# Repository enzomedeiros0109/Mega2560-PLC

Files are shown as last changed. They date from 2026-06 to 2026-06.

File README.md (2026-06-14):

# Placa de Circuito Impresso

| Esquemático | Visão Superior (Top) | Visão Inferior (Bottom) |
| :---: | :---: | :---: |
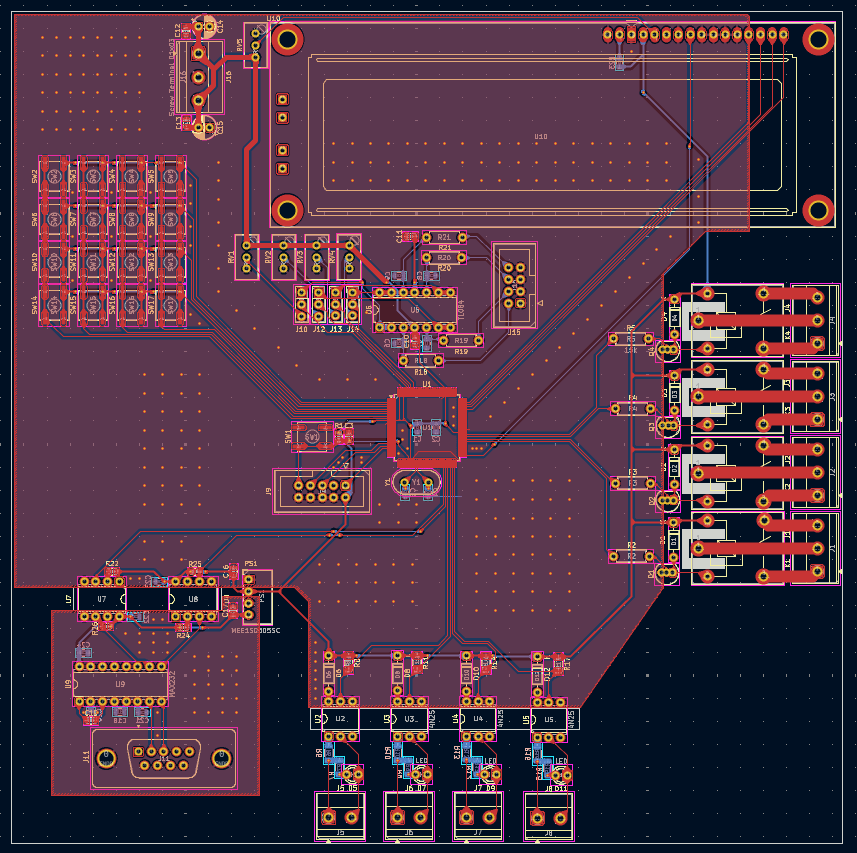
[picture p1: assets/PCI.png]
Esquemático da Placa de Circuito Impresso
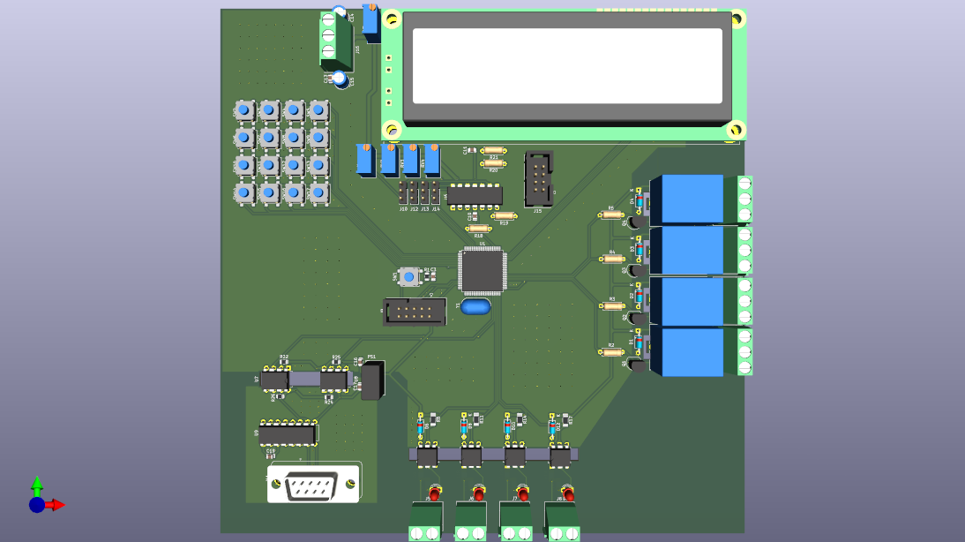
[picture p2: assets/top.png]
Visualização 3D da parte superior da PCB
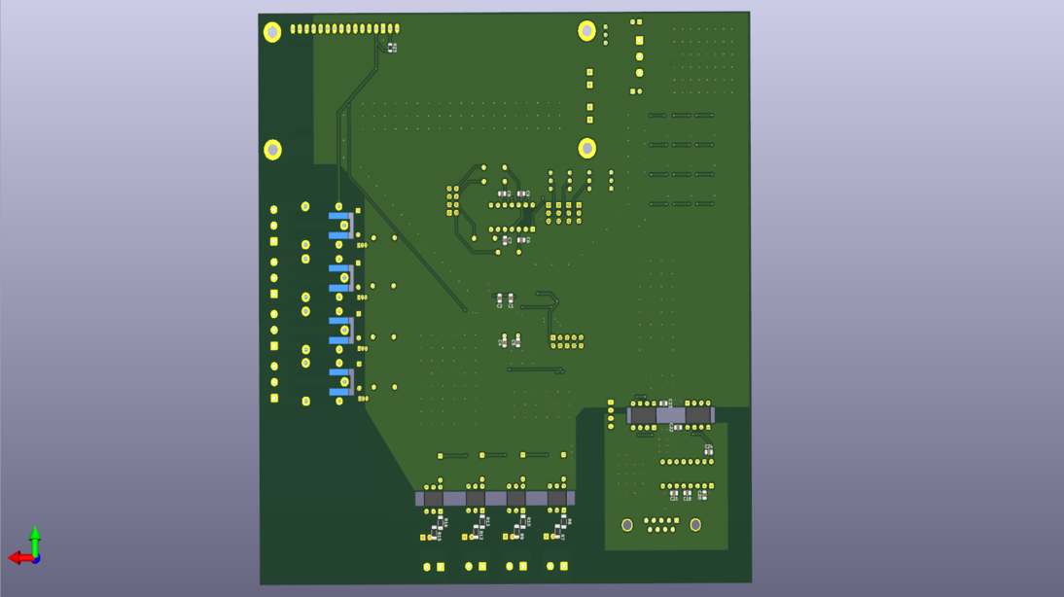
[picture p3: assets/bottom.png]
Visualização 3D da parte inferior da PCB
|  |  |  |

## Descrição

Este projeto consiste no design de uma Placa de Circuito Impresso (PCB) voltada para aplicações de controle, automação e desenvolvimento. A placa integra diversas interfaces de entrada, saída e comunicação em um único hardware, tornando-a ideal para controle de processos industriais, automação residencial ou projetos acadêmicos avançados.

## Principais Recursos

Essa placa foi o projeto final da cadeira de Construção de Dispositivos Digitais do curso de Engenharia da Computação. Ela contém:

* **Processamento Central:** Espaço dedicado para o microcontrolador principal (U1) com pinos de programação/debug e cristal oscilador (Y1).
* **Interface de Usuário (IHM):**
    * **Teclado Matricial 4x4:** Matriz de 16 botões (SW2 a SW17) para entrada de dados e navegação.
    * **Display LCD:** Interface no topo da placa (U10) para conexão de displays LCD (ex: 16x2 ou 20x4).
* **Acionamento de Potência:**
    * **4x Relés Independentes:** (K1 a K4) com conectores tipo borne para acionamento seguro de cargas AC/DC externas.
* **Isolamento e Segurança:**
    * **Entradas/Saídas Optoisoladas:** CI's dedicados (U2 a U5) para proteção do circuito lógico contra ruídos e picos de tensão das interfaces externas.
* **Comunicação:**
    * **Porta Serial RS-232:** Conector DB9 (J11) em conjunto com o driver MAX232 (U9) para comunicação com CLP's, computadores e equipamentos legados.
* **Tratamento de Sinais Analógicos:**
    * Circuito com Amplificador Operacional (TL084 - U6) e múltiplos trimpots (RV1 a RV4) para calibração, condicionamento e ajuste de ganhos de sensores analógicos.
* **Conectividade:**
    * Múltiplos terminais de parafuso (screw terminals) nas bordas da placa para facilitar a ligação de sensores, fontes de alimentação e atuadores.

## Características do projeto

* **Software:** KiCAD
* **Camadas:** Placa de dupla face (Top e Bottom layers visíveis pelas trilhas vermelhas e azuis).

## Estrutura do Projeto

```text
├── assets/
│   └── schematic_view.jpeg   # Imagens e renderizações da placa
│   └── top_view.jpeg         # Parte superior da placa
│   └── bottom_view.jpeg      # Parte inferior da placa
├── gerbers                   # Arquivos para fabricação da PCB
├── pasta do projeto          # Pasta com projeto KiCAD
└── Planilha de preços.ods    # Planilha com preço e link dos componentes
```

## Como abrir o arquivo

1. Faça o clone do repositório.
2. Acesse a pasta `pasta do projeto` abra `av3.kicad_pro`.

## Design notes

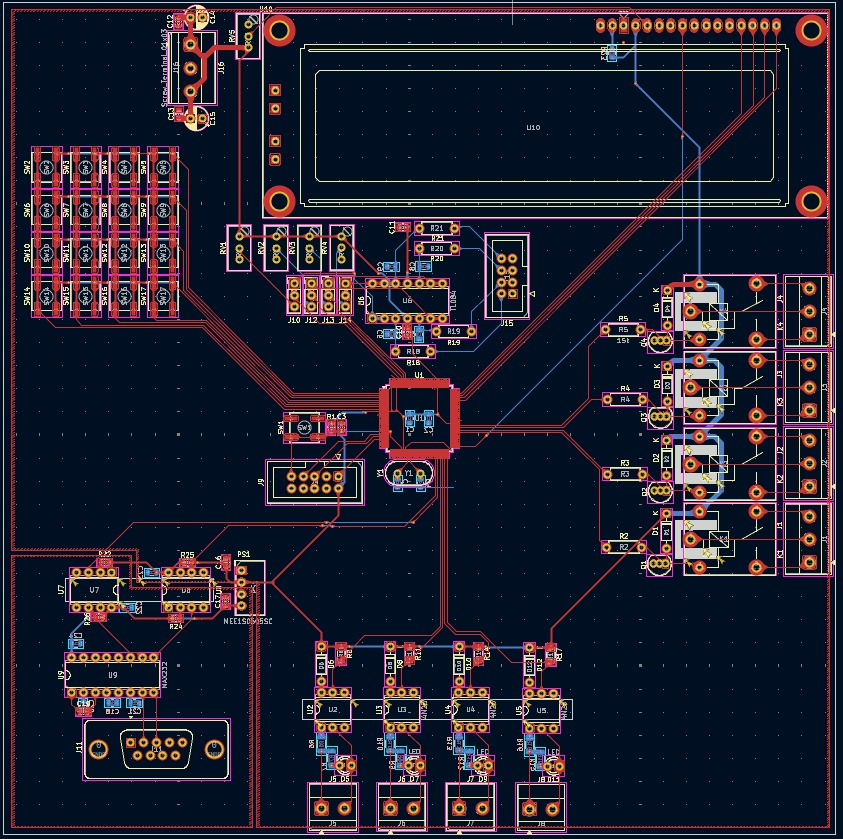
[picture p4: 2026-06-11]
assets/schematic_view.jpeg

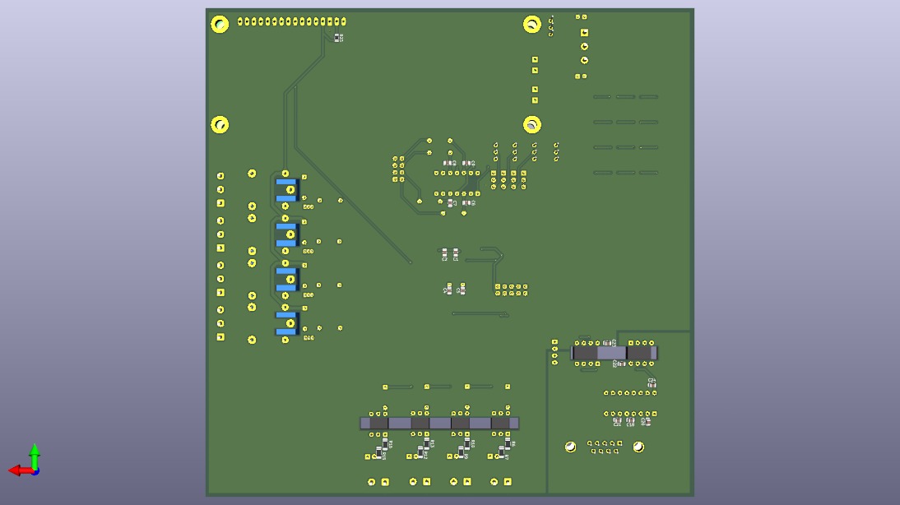
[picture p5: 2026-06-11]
assets/bottom_view.jpeg

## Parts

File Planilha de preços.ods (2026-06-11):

Footprint |  | Valores | Qtd na placa | Preço (Reais) | Qtd na compra | Custo total por componente (Reais) | Site
Capacitor_SMD | C_0805_2012Metric | 100nF | 16 | 19,16 | 100 | 3,07 | https://www.mercadolivre.com.br/100-pcs--capacitor-ceramico-smd-0805-100nf-50v-01uf/up/MLBU3922269514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 | Custo das Peças
Capacitor_SMD | C_0805_2012Metric | 22pF | 2 | 14,63 | 50 | 0,59 | https://www.mercadolivre.com.br/50x-capacitor-22pf50v-0603-smd-08x16mm-np0-samsung/up/MLBU1429310606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
Capacitor_THT | CP_Radial_D5.0mm_P2.50mm | 10uF/16V | 2 | 13,90 | 10 | 2,78 | https://www.mercadolivre.com.br/capacitor-eletrolitico-10uf-50v--10-pecas/up/MLBU1740482830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 | 416,68462
Capacitor_SMD | C_0805_2012Metric | 1uF | 4 | 19,90 | 100 | 0,80 | https://www.mercadolivre.com.br/kit-100-pecas-capacitor-ceramico-smd-0805-1uf-25v-x7r-10/up/MLBU3756911618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
Diode_THT | D_DO-35_SOD27_P7.62mm_Horizontal | 1N4148 | 8 | 74,99 | 1000 | 0,60 | https://www.mercadolivre.com.br/diodo-de-sinal-1n4148-do35-fitado-1000-pecas/up/MLBU1162432908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
LED_THT | LED_D3.0mm | LED | 4 | 12,99 | 100 | 0,52 | https://www.mercadolivre.com.br/led-3mm-vermelho-difuso-comum-pacote-100-pecas/up/MLBU596105315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 | Custo da PCB (PCBWay)
TerminalBlock_Phoenix | TerminalBlock_Phoenix_MKDS-1,5-3_1x03_P5.00mm_Horizontal | Conn_01x03 | 4 | 20,00 | 10 | 8,00 | https://www.mercadolivre.com.br/10-pecas--borne-kre-3vias-verde-kf1283t-508mm-promocao/up/MLBU1425091365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
TerminalBlock_Phoenix | TerminalBlock_Phoenix_MKDS-1,5-2_1x02_P5.00mm_Horizontal | Conn_01x02 | 4 | 19,00 | 10 | 7,60 | https://www.mercadolivre.com.br/borne-kre-2vias-verde-kf1282t-508mm-kit-c10pcs-oferta/up/MLBU1721454400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 | 88,13
Connector_IDC | IDC-Header_2x05_P2.54mm_Vertical | Conn_02x05_Odd_Even | 1 | 30,00 | 10 | 3,00 | https://www.mercadolivre.com.br/10pc-conector-idc-10vias-de-transicao-idct10-passo-254mm/up/MLBU4009714486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
Connector_PinHeader_2.54mm | PinHeader_1x03_P2.54mm_Vertical | Conn_01x03 | 4 | 16,99 | 50 | 1,36 | https://www.mercadolivre.com.br/10pc-conector-idc-10vias-de-transicao-idct10-passo-254mm/up/MLBU4009714486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
Connector_Dsub | DSUB-9_Pins_Vertical_P2.77x2.84mm_MountingHoles | DE9_Pins_MountingHoles | 1 | 7,68 | 1 | 7,68 | https://www.metabee.com/renhotec-d-sub-9-pin-standard-male-connector-for-pcb-mount-through-hole-2-77mm-pitch.html | Custo total
Connector_IDC | IDC-Header_2x04_P2.54mm_Vertical | Conn_02x04_Odd_Even | 1 | 2,17 | 1 | 2,17 | https://www.elecbee.com/en/product-detail/elecbee-wire-to-board-pin-header-2-54mm-pitch-2x4pin-through-hole-straight-pbt-black_137516
TerminalBlock_Phoenix | TerminalBlock_Phoenix_MKDS-1,5-3-5.08_1x03_P5.08mm_Horizontal | Screw_Terminal_01x03 | 1 | 20,00 | 10 | 2,00 | https://www.mercadolivre.com.br/10-pecas--borne-kre-3vias-verde-kf1283t-508mm-promocao/up/MLBU1425091365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 | 504,81462
Relay_THT | Relay_SPDT_SANYOU_SRD_Series_Form_C | SANYOU_SRD_Form_C | 4 | 27,51 | 8 | 13,76 | https://www.mercadolivre.com.br/8-reles-srd-12v-10a-5-pinos-arduino/up/MLBU3628947135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
Converter_DCDC | Converter_DCDC_Murata_CRE1xxxxxxSC_THT | MEE1S0505SC | 1 | 23,94 | 1 | 23,94 | https://www.sager.com/product/mee1s0505sc-murata-power-solutions/3810040
Package_TO_SOT_THT | TO-92_Inline | BC337 | 4 | 10,99 | 10 | 4,40 | https://www.mercadolivre.com.br/kit-com-10---bc33725-transistor-to92-npn-45v-800ma-bipola/up/MLBU3248955014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
Resistor_SMD | R_0805_2012Metric | 10K | 6 | 12,54 | 100 | 0,75 | https://www.mercadolivre.com.br/100x-resistor-10k-0805-5-smd-125x2mm/up/MLBU2220601703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
Resistor_THT | R_Axial_DIN0207_L6.3mm_D2.5mm_P7.62mm_Horizontal | 15K | 4 | 19,90 | 100 | 0,80 | https://www.mercadolivre.com.br/kit-100-unidades-resistor-15k-5-14w/up/MLBU3013017251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
Resistor_SMD | R_1206_3216Metric_Pad1.30x1.75mm_HandSolder | 100 | 8 | 11,50 | 30 | 3,07 | https://www.mercadolivre.com.br/30x-resistor-100r-1206-5-smd-16x32mm/up/MLBU1443383442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
Resistor_SMD | R_1206_3216Metric_Pad1.30x1.75mm_HandSolder | 10K | 4 | 19,90 | 30 | 2,65 | https://www.mercadolivre.com.br/10k-30-pecasresistor-smd-10k-1-1206-32mm-x16mm-1002/up/MLBU2905965901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
Resistor_THT | R_Axial_DIN0207_L6.3mm_D2.5mm_P7.62mm_Horizontal | 10K | 4 | 18,90 | 200 | 0,38 | https://www.mercadolivre.com.br/kit-200-unidades-resistor-10k-5-14w/up/MLBU1966352837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
Potentiometer_THT | Potentiometer_Bourns_3296W_Vertical | 10K | 5 | 18,42 | 10 | 9,21 | https://www.mercadolivre.com.br/10-pecas-trimpot-3296w-10k-vertical-multivoltas-promoco/p/MLB2076037856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
Button_Switch_SMD | SW_Push_1P1T_NO_CK_KSC7xxJ | SW_Omron_B3FS | 17 | 23,41 | 100 | 3,98 | https://www.mercadolivre.com.br/100-pecas-micro-chave-push-button-4-pinos-protoboard-6x6x75/up/MLBU3016057330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
Package_QFP | TQFP-100_14x14mm_P0.5mm | ATmega2560-16A | 1 | 106,20 | 1 | 106,20 | https://www.multcomercial.com.br/microcontrolador-atmega2560-16au-tqfp100-atmel.html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
Package_DIP | DIP-6_W7.62mm | 4N25 | 4 | 35,00 | 10 | 14,00 | https://www.mercadolivre.com.br/ci-4n25--optoacoplador--dip--kit--10-pecas/up/MLBU1437719580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
Package_DIP | DIP-14_W7.62mm | TL084 | 1 | 30,98 | 10 | 3,10 | https://www.mercadolivre.com.br/circuito-integrado-de-10-pecas-tl084-dip-14-amplificador/p/MLB2076906861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
Package_DIP | DIP-8_W7.62mm | 6N137 | 2 | 35,99 | 5 | 14,40 | https://www.mercadolivre.com.br/5-pecas-ci-6n137-dip8-everligth/p/MLB53255257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
Package_DIP | DIP-16_W7.62mm | MAX232 | 1 | 42,08 | 10 | 4,21 | https://www.mercadolivre.com.br/10x-circuito-integrado-max232cpe-max232-max232n-dip16/up/MLBU3335206018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
Display | LCD-016N002L | LCD-016N002L | 1 | 170,96 | 1 | 170,96 | https://www.proesi.com.br/display-lcd-winstar-wh-1602l-tmi-jt-16x2-big-number-com-back-azul
Crystal | Resonator-2Pin_W10.0mm_H5.0mm | 16Mhz | 1 | 37,00 | 50 | 0,74 | https://www.mercadolivre.com.br/50x-cristal-hc49s-16-mhz/up/MLBU731193518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

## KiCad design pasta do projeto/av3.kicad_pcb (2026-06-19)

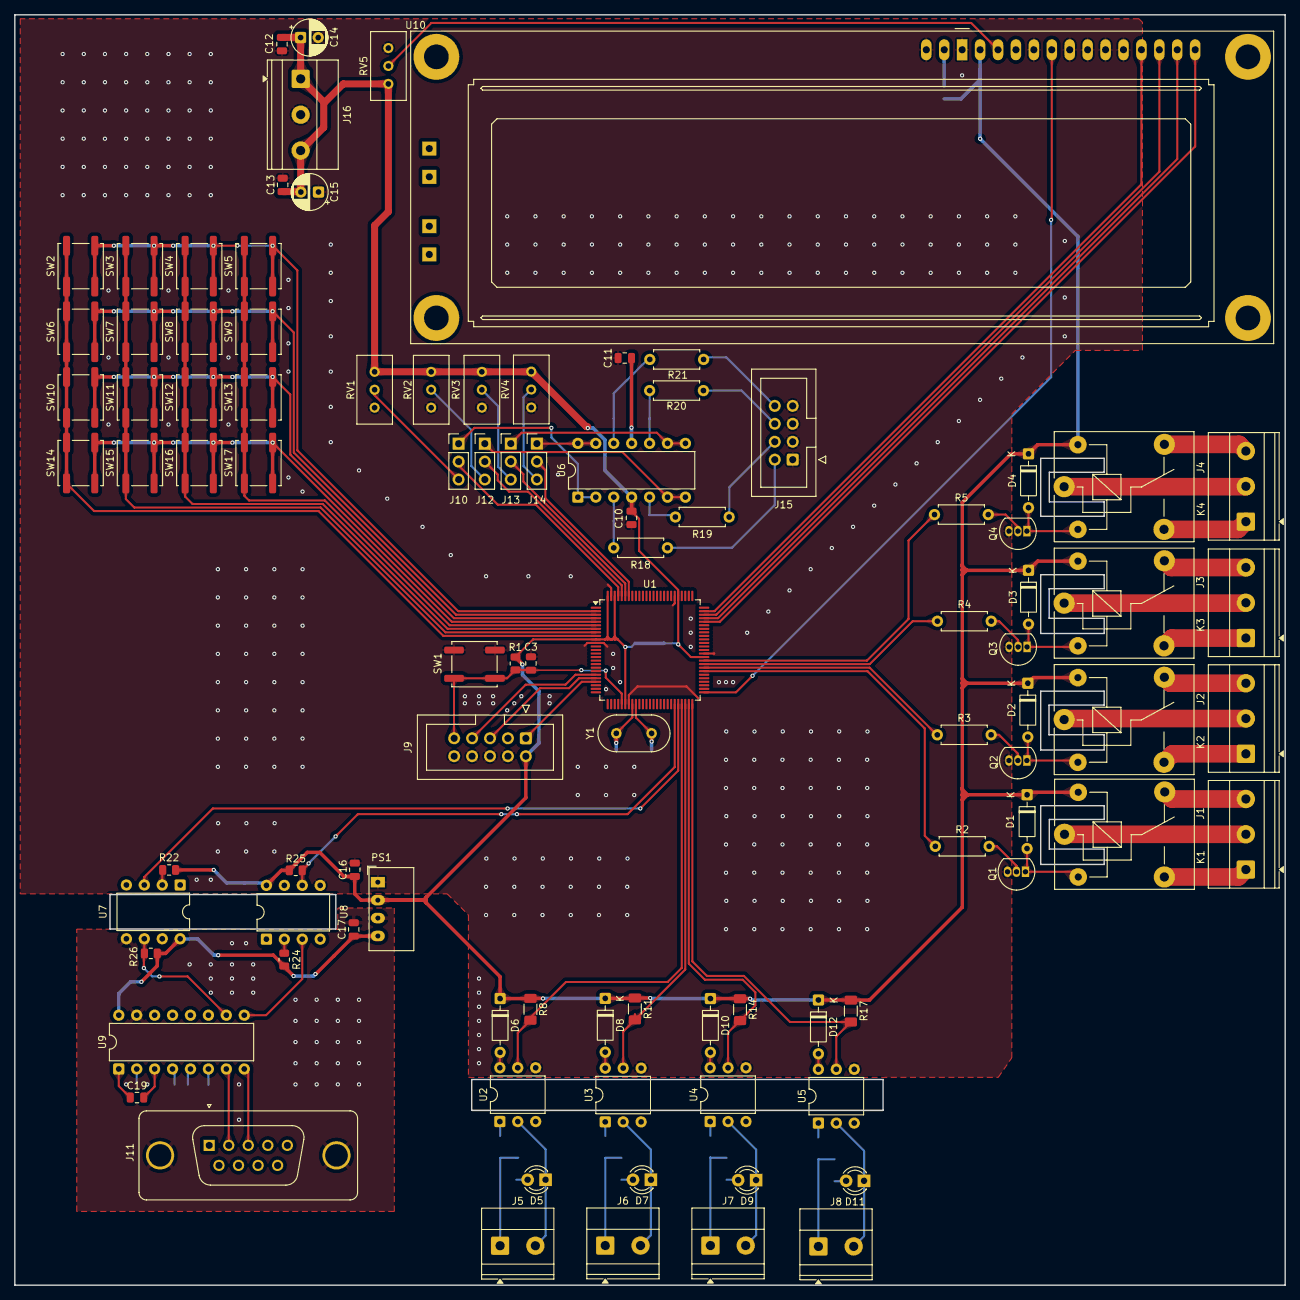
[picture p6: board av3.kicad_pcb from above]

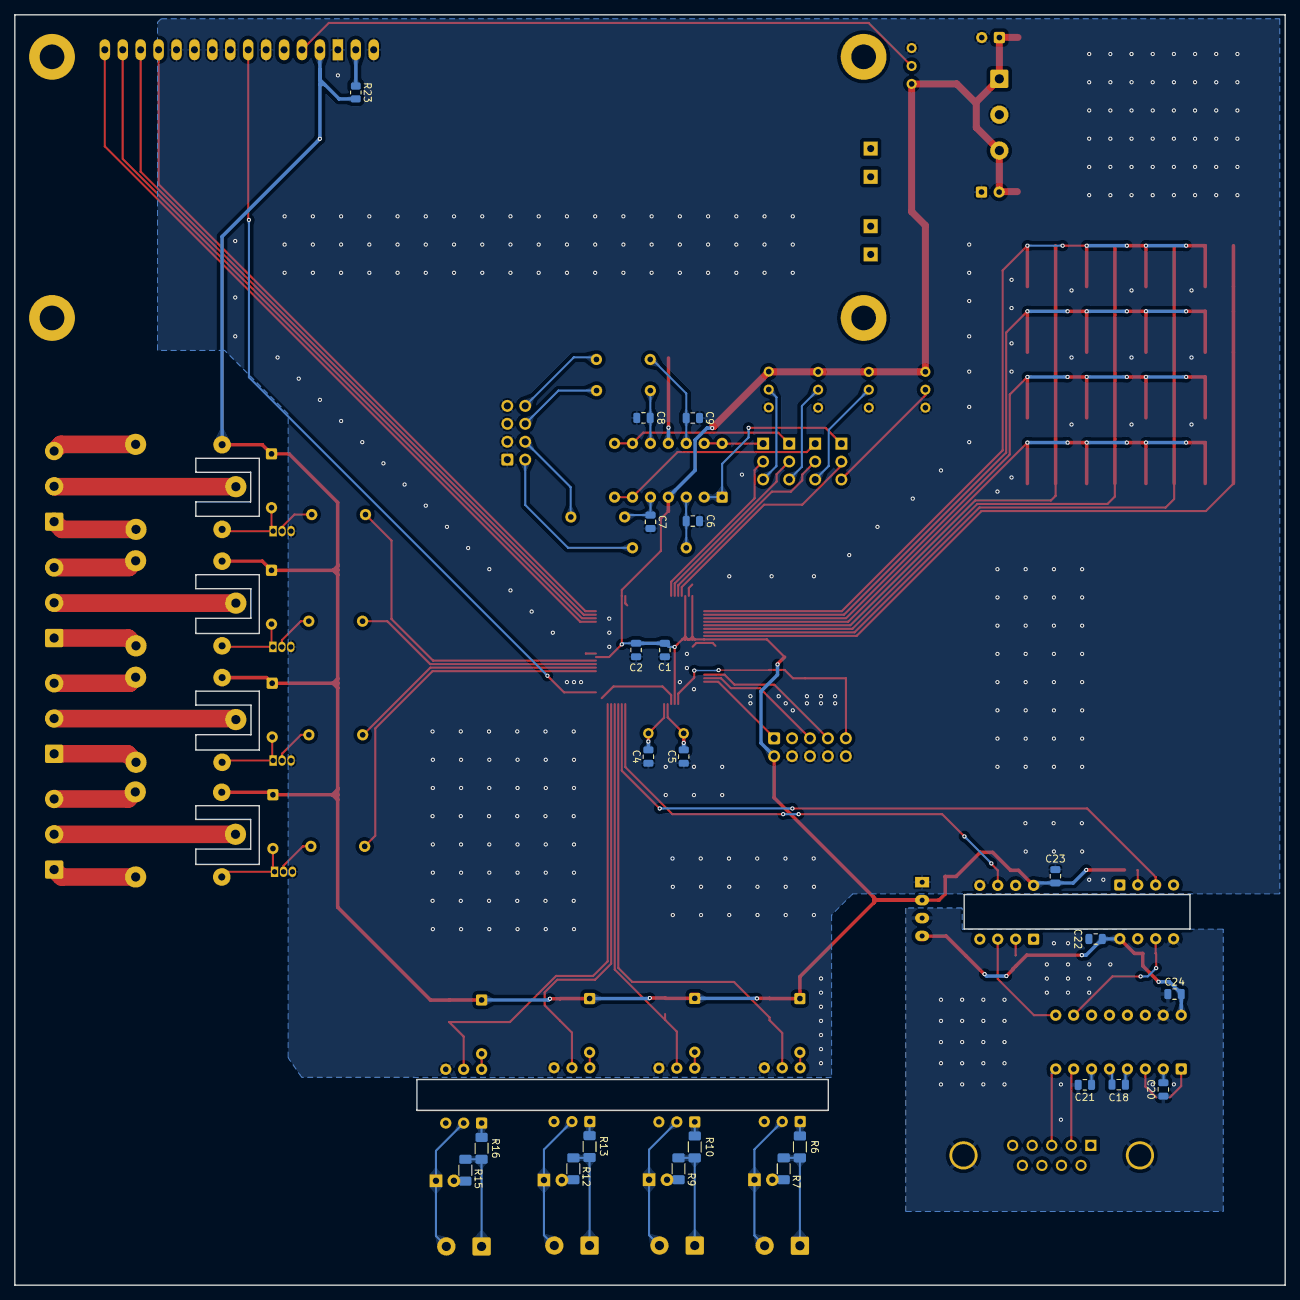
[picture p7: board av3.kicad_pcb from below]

Board: 2 copper layers, 180.0 x 180.0 mm, 120 parts (23 on the bottom side), 108 nets.

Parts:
C1, C2, C3, C6, C7, C8, C9, C10, C11, C12, C13, C16, C17, C22, C23, C24: 100nF; C_0805_2012Metric
C4, C5: 22pF; C_0805_2012Metric
C14, C15: 10uF/16V; CP_Radial_D5.0mm_P2.50mm
C18, C19, C20, C21: 1uF; C_0805_2012Metric
D1, D2, D3, D4, D6, D8, D10, D12: 1N4148; D_DO-35_SOD27_P7.62mm_Horizontal
D5, D7, D9, D11: LED; LED_D3.0mm
J1, J2, J3, J4: Conn_01x03; TerminalBlock_Phoenix_MKDS-1,5-3_1x03_P5.00mm_Horizontal
J5, J6, J7, J8: Conn_01x02; TerminalBlock_Phoenix_MKDS-1,5-2_1x02_P5.00mm_Horizontal
J9: Conn_02x05_Odd_Even; IDC-Header_2x05_P2.54mm_Vertical
J10, J12, J13, J14: Conn_01x03; PinHeader_1x03_P2.54mm_Vertical
J11: DE9_Pins_MountingHoles; DSUB-9_Pins_Vertical_P2.77x2.84mm_MountingHoles
J15: Conn_02x04_Odd_Even; IDC-Header_2x04_P2.54mm_Vertical
J16: Screw_Terminal_01x03; TerminalBlock_Phoenix_MKDS-1,5-3-5.08_1x03_P5.08mm_Horizont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
K1, K2, K3, K4: SANYOU_SRD_Form_C; Relay_SPDT_SANYOU_SRD_Series_Form_C
PS1: MEE1S0505SC; Converter_DCDC_Murata_CRE1xxxxxxSC_THT
Q1, Q2, Q3, Q4: BC337; TO-92_Inline
R1, R24, R26: 10k; R_0805_2012Metric
R2, R3, R4, R5: 15k; R_Axial_DIN0207_L6.3mm_D2.5mm_P7.62mm_Horizontal
R6, R7, R9, R10, R12, R13, R15, R16: 100; R_1206_3216Metric_Pad1.30x1.75mm_HandSolder
R8, R11, R14, R17: R; R_1206_3216Metric_Pad1.30x1.75mm_HandSolder
R18, R19, R20, R21: 10K; R_Axial_DIN0207_L6.3mm_D2.5mm_P7.62mm_Horizontal
R22, R23, R25: 10K; R_0805_2012Metric
RV1, RV2, RV3, RV4, RV5: 10k; Potentiometer_Bourns_3296W_Vertical
SW1, SW2, SW3, SW4, SW5, SW6, SW7, SW8, SW9, SW10, SW11, SW12, SW13, SW14, SW15, SW16, SW17: SW_Omron_B3FS; SW_Push_1P1T_NO_CK_KSC7xxJ
U1: ATmega2560-16A; TQFP-100_14x14mm_P0.5mm
U2, U3, U4, U5: 4N25; DIP-6_W7.62mm
U6: TL084; DIP-14_W7.62mm
U7, U8: 6N137; DIP-8_W7.62mm
U9: MAX232; DIP-16_W7.62mm
U10: LCD-016N002L
Y1: 16Mhz; Resonator-2Pin_W10.0mm_H5.0mm

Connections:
+5V: C1.2, C2.1, C10.1, C12.1, C13.2, C14.1, C15.2, C16.1, C23.2, D1.1 (K), D2.1 (K), D3.1 (K), D4.1 (K), D6.1 (K), D8.1 (K), D10.1 (K), D12.1 (K), J9.2, J16.1, J16.3, K1.5, K2.5, K3.5, K4.5, PS1.2 (+Vin), R1.1, R8.1, R11.1, R14.1, R17.1, R22.1, R23.2, R25.1, RV1.1, RV2.1, RV3.1, RV4.1, RV5.3, U1.10 (VCC), U1.31 (VCC), U1.61 (VCC), U1.80 (VCC), U1.98 (AREF), U1.100 (AVCC), U6.4 (V+), U8.8 (VCC), U10.2 (VDD)
+5VD: C17.1, C22.1, C24.1, PS1.4 (+Vout), R24.1, R26.2, U7.8 (VCC), U9.16 (VCC)
-5V: C11.1, U6.11 (V-)
A0: J15.2, R18.1
A1: J15.4, R19.1
A2: J15.6, R20.1
A3: J15.8, R21.1
ADC0: J10.2, U1.97 (PF0)
ADC1: J12.2, U1.96 (PF1)
ADC2: J13.2, U1.95 (PF2)
ADC3: J14.2, U1.94 (PF3)
C1: SW5.2, SW9.2, SW13.2, SW17.2, U1.6 (PE4)
C2: SW4.2, SW8.2, SW12.2, SW16.2, U1.7 (PE5)
C3: SW3.2, SW7.2, SW11.2, SW15.2, U1.8 (PE6)
C4: SW2.2, SW6.2, SW10.2, SW14.2, U1.9 (PE7)
D4: U1.74 (PA4), U10.11 (DB4)
D5: U1.73 (PA5), U10.12 (DB5)
D6: U1.72 (PA6), U10.13 (DB6)
D7: U1.71 (PA7), U10.14 (DB7)
E: U1.51 (PG0), U10.6 (E)
GND: C1.1, C2.2, C3.1, C4.1, C5.1, C6.2, C7.2, C8.2, C9.2, C10.2, C11.2, C12.2, C13.1, C14.2, C15.1, C16.2, C23.1, J9.4, J9.6, J9.8, J9.10, J15.1, J15.3, J15.5, J15.7, J16.2, PS1.1 (-Vin), Q1.3 (E), Q2.3 (E), Q3.3 (E), Q4.3 (E), RV1.3, RV2.3, RV3.3, RV4.3, RV5.1, SW1.1, U1.11 (GND), U1.32 (GND), U1.62 (GND), U1.81 (GND), U1.99 (GND), U2.4, U3.4, U4.4, U5.4, U8.5 (GND), U10.1 (VSS), U10.5 (R/~W), U10.7 (DB0), U10.8 (DB1), U10.9 (DB2), U10.10 (DB3), U10.16 (K)
GNDD: C17.2, C20.2, C21.2, C24.2, J11.0 (PAD), PS1.3 (-Vout), U7.5 (GND), U9.15 (GND)
L1: SW2.1, SW3.1, SW4.1, SW5.1, U1.2 (PE0)
L2: SW6.1, SW7.1, SW8.1, SW9.1, U1.3 (PE1)
L3: SW10.1, SW11.1, SW12.1, SW13.1, U1.4 (PE2)
L4: SW14.1, SW15.1, SW16.1, SW17.1, U1.5 (PE3)
MISO: J9.1, U1.22 (PB3)
MOSI: J9.5, U1.21 (PB2)
unnamed: D1.2 (A), K1.2, Q1.1 (C)
unnamed: D2.2 (A), K2.2, Q2.1 (C)
unnamed: D3.2 (A), K3.2, Q3.1 (C)
unnamed: D4.2 (A), K4.2, Q4.1 (C)
unnamed: D5.2 (A), R7.2
unnamed: D5.1 (K), J5.2, U2.2
unnamed: D6.2 (A), U2.6
unnamed: D7.2 (A), R9.2
unnamed: D7.1 (K), J6.2, U3.2
unnamed: D8.2 (A), U3.6
unnamed: D9.2 (A), R12.2
unnamed: D9.1 (K), J7.2, U4.2
unnamed: D10.2 (A), U4.6
unnamed: D11.2 (A), R15.2
unnamed: D11.1 (K), J8.2, U5.2
unnamed: D12.2 (A), U5.6
unnamed: J1.1, K1.3
unnamed: J1.2, K1.1
unnamed: J1.3, K1.4
unnamed: J2.1, K2.3
unnamed: J2.2, K2.1
unnamed: J2.3, K2.4
unnamed: J3.1, K3.3
unnamed: J3.2, K3.1
unnamed: J3.3, K3.4
unnamed: J4.1, K4.3
unnamed: J4.2, K4.1
unnamed: J4.3, K4.4
unnamed: J5.1, R6.1, R7.1
unnamed: J6.1, R9.1, R10.1
unnamed: J7.1, R12.1, R13.1
unnamed: J8.1, R15.1, R16.1
unnamed: J10.1, U6.1, U6.2 (-)
unnamed: J12.1, U6.6 (-), U6.7
unnamed: J13.1, U6.8, U6.9 (-)
unnamed: J14.1, U6.13 (-), U6.14
unnamed: Q1.2 (B), R2.2
unnamed: Q2.2 (B), R3.2
unnamed: Q3.2 (B), R4.2
unnamed: Q4.2 (B), R5.2
unnamed: R6.2, U2.1
unnamed: R10.2, U3.1
unnamed: R13.2, U4.1
unnamed: R16.2, U5.1
unnamed: C4.2, U1.34 (XTAL1), Y1.2
unnamed: C5.2, U1.33 (XTAL2), Y1.1
unnamed: C6.1, R18.2, U6.3 (+)
unnamed: C7.1, R19.2, U6.5 (+)
unnamed: C8.1, R20.2, U6.10 (+)
unnamed: C9.1, R21.2, U6.12 (+)
unnamed: R22.2, U7.2 (A)
unnamed: R26.1, U7.6 (VO), U9.10 (T2IN)
unnamed: R24.2, U8.2 (A)
unnamed: U8.3 (C), U9.9 (R2OUT)
unnamed: C19.1, U9.1 (C1+)
unnamed: C19.2, U9.3 (C1-)
unnamed: C18.1, U9.4 (C2+)
unnamed: C18.2, U9.5 (C2-)
unnamed: J11.3, U9.8 (R2IN)
unnamed: J11.2, U9.7 (T2OUT)
unnamed: C20.1, U9.2 (VS+)
unnamed: C21.1, U9.6 (VS-)
unnamed: R23.1, U10.15 (A/VEE)
unnamed: RV5.2, U10.3 (VO)
RST: C3.2, J9.9, R1.2, SW1.2, U1.30 (~RESET)
RX: R25.2, U1.45 (PD2), U8.6 (VO)
SCK: J9.7, U1.20 (PB1)
TX: U1.46 (PD3), U7.3 (C)
in0.1: R8.2, U1.47 (PD4), U2.5
in0.2: R11.2, U1.48 (PD5), U3.5
in0.3: R14.2, U1.49 (PD6), U4.5
in0.4: R17.2, U1.50 (PD7), U5.5
pot1: J10.3, RV1.2
pot2: J12.3, RV2.2
pot3: J13.3, RV3.2
pot4: J14.3, RV4.2
q0.1: R2.1, U1.57 (PC4)
q0.2: R3.1, U1.58 (PC5)
q0.3: R4.1, U1.59 (PC6)
q0.4: R5.1, U1.60 (PC7)

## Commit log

2026-05-10 FEAT: Adiciona as folhas de projeto restantes (reles, modulo_entrada e condicionamento_sinal)
    [av3.kicad_sch, condicionamento_sinal.kicad_sch, modulo_entrada.kicad_sch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]
2026-05-13 FEAT: Adição das footprints dos capacitores (C) e screw_terminals (J)
    [condicionamento_sinal.kicad_sch, microcontrolador.kicad_sch, modulo_entrada.kicad_sch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]
2026-05-27 Alteração do footprint do PS1 e inicio da PCB
    [av3.kicad_pcb, condicionamento_sinal.kicad_sch, microcontrolador.kicad_sch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]
2026-05-28 Mudança de footprints e mudança na PCB
    [av3.kicad_pcb, condicionamento_sinal.kicad_sch, microcontrolador.kicad_sch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]
2026-06-02 Algumas trilhas feitas
    [av3.kicad_pcb, condicionamento_sinal.kicad_sch, modulo_entrada.kicad_sch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]
2026-06-03 Finaliza a organização dos componentes na PCB, ajusta footprints
    [av3.kicad_pcb, condicionamento_sinal.kicad_sch, microcontrolador.kicad_sch]
2026-06-07 Orçamento de montagem e outros orçamentos
    [Planilha de preços.ods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]
2026-06-11 Finalização do orçamento e das malhas
    [Planilha de preços.ods]
2026-06-11 final, final mesmo
    [av3.kicad_pcb]
2026-06-13 Corrige malha de ground, trilhas dos relés e tensão, adiciona furos na placa
    [av3.kicad_pcb]
2026-06-13 Alterações nas malhas GND/GNDD, mudança de trilha nos relés, tensão e adição de furos na placa
2026-06-14 Corrige erro da PCI
    [av3.kicad_pcb]
2026-06-19 Remove vias dos pads de componentes SMD e corrige caminho de trilhas
    [av3.kicad_pcb]
